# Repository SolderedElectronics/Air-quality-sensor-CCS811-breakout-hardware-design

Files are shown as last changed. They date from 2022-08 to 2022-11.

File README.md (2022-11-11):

# Air quality sensor CCS811 breakout Hardware design

## About the product

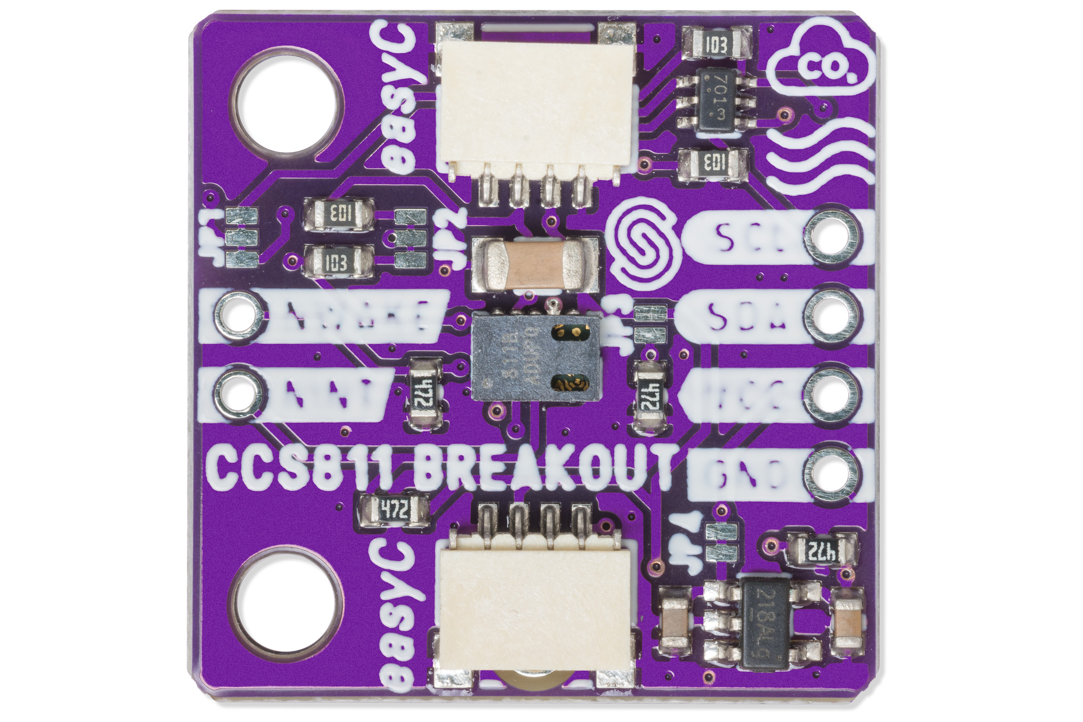
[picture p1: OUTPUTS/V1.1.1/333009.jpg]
Air quality sensor CCS811 breakout
|  |
| :----------------------------------------------------------: |
|      [Buy Air quality sensor CCS811 breakout](https://www.solde.red/333009)      |

The CCS811 sensor is designed to measure various volatile particles in the air (TVOC - Total Volatile Organic Compounds), which include eCO2 (CO2 equivalent) and MOX (metal oxides). VOCs are generally defined as air pollutants, and can come from a variety of sources, starting with ordinary breathing, smoking, coloring, welding, and generally all processes that release particles into the surrounding air.

This sensor is often used to measure indoor air quality, which can work very well and indicate current air pollution, for example, in an office. It communicates via I2C, making it easy to connect, especially through easyC. Sensor itself should be powered for at least 20 minutes to start making accurate readings.

## Repository contents

All Soldered Electronics hardware designed in KiCAD, and repositories are organized in the following way:

- CAD folder - contains KiCAD files (Schematics, Board, Panel Board), sorted by version. Change log lists all changes between versions.
- OUTPUTS - contains useful files, such as Bill of Materials (BOM), PDF of schematics, 3D .step file of the board and gerber files, sorted by version. 
- OUTPUTS -> Compliance - Certificates and useful legal stuff. 

## Want to contribute?

Please feel free to submit a pull request if you have any contributions. We encourage you to submit an issue or pull request if you find a bug. 

## About Soldered

soldered-logo

At Soldered, we design and manufacture a wide selection of electronic products to help you turn your ideas into acts and bring you one step closer to your final project. Our products are intented for makers and crafted in-house by our experienced team in Osijek, Croatia. We believe that sharing is a crucial element for improvement and innovation, and we work hard to stay connected with all our makers regardless of their skill or experience level. Therefore, all our products are open-source. Finally, we always have your back. If you face any problem concerning either your shopping experience or your electronics project, our team will help you deal with it, offering efficient customer service and cost-free technical support anytime. Some of those might be useful for you:

- [Web Store](https://www.soldered.com/shop)
- [Tutorials & Projects](https://soldered.com/learn)
- [Community & Technical support](https://soldered.com/community)

## License info

All Soldered open-source hardware (OSH) is under The TAPR Open Hardware License. Read more in the LICENSE file. 

No warranty - all designs in this repository are distributed in the hope that they will be useful, but without any warranty. They are provided "AS IS", therefore without warranty of any kind, either expressed or implied. The entire quality and performance of what you do with the contents of this repository are your responsibility. In no event, Soldered Electronics will be liable for your damages, losses, including any general, special, incidental or consequential damage arising out of the use or inability to use the contents of this repository. 

## Have fun! 
And thank you from your fellow makers at Soldered Electronics.

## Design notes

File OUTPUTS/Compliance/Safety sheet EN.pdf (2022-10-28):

## Regulatory Compliance and Important Safety Information

PLEASE RETAIN THIS INFORMATION FOR FUTURE REFERENCE.

BEFORE USING THIS PRODUCT, READ ALL INSTRUCTION IN THIS DOCUMENT.

Product name: | Air quality sensor CCS811 breakout
Getting started: | To get started, please visit www.soldered.com

# WARNINGS

- This product should not be covered and should be operated in well ventilated enviroment.
- The product should be placed on a stable, flat, non-conductive surface and should not be contacted by conductive items.
- Connection of other devices may affect compliance or result in damage to the unit, and invalidate the warranty.
- Where peripherals are connected that do not include the cable or connector, the cable or connector used must offer adequate insulation and operation in order that the requirements of the relevant performance and safety requirements are met.
- There is a danger of explosion if the battery is incorrectly placed.
- The product should not be used outside of its specified working range.

# INSTRUCTIONS FOR SAFE USE

To avoid malfunction or damage to your device, please observe the following:
- Do not expose it to water, moisture or place on a conductive surface when turned on. Do not handle the unit with wet hands.
- Do not expose it to heat from any source; the product is designed to be used at normal ambient room temperatures. The product is intended to be used inside.
- Take care when handling to avoid mechanical or electrical damage to any part of the unit. Avoid handling the unit while it's powered. Use ESD protection.
- Use only supplied cable (or the cable of the same or higher quality) with the unit.

# COMPLIANCE INFORMATION

The product complies with the relevant provision of the RoHS Directive for the European Union. In common with all Electrical and Electronic Equipment (EEE), the product should not be disposed household waste.

ELECTROMAGNETIC COMPABILITY AND OPERATION

- The product is in conformity with the protection requirements of EU Council Directive 2014/30/EU on the laws of the Member States relating of electromagnetic compability, and Electromagnetic Compability Regulations 2016 of the UK.
- WARNING: Please do not alter the design of this product, doing so may void your ability to use the product freely, this includes altering the frequency at which product operates.

Soldered Electronics d.o.o., Reisnerova ulica 100, 31000 Osijek, Croatia. VAT ID: HR83200237288

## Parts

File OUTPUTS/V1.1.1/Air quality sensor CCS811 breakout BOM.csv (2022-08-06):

Id | Designator | Package | Quantity | Designation | Supplier and ref
1 | ,,,,,,,,,,,, | buzzardLabel | 13
2 | C1 | 1206C | 1 | 10uF
3 | G*** | Logo-Back-OSH-3.5mm | 1 | LOGO
4 | G*** | Logo-Front-Soldered-3mm | 1 | LOGO
5 | R6,R1,R2,R5 | 0603R | 4 | 4.7k
6 | JP2,JP1 | SMD_JUMPER_3_PAD_TRACE | 2 | SMD_JUMPER_3_PAD_TRACE
7 | R4,R7,R3,R8 | 0603R | 4 | 10k
8 | G*** | Symbol-Front-Air-Quality | 1 | LOGO
9 | JP4 | SMD-JUMPER-CONNECTED_TRACE_SLODERMASK | 1 | SMD-JUMPER-CONNECTED_TRACE_SLODERMASK
10 | U3 | SOT-23-5 | 1 | SE5218
11 | G***,G*** | Logo-Front-easyC-5mm | 2 | LOGO
12 | FD1 | FIDUCIAL_23 | 1 | FIDUCIAL
13 | K3,K4 | easyC-connector | 2 | easyC-SMD
14 | G*** | Symbol-Front-CO2 | 1 | LOGO
15 | C3,C2 | 0603C | 2 | 2.2uF
16 | REF** | Logo-Back-SolderedFULL-15mm | 1 | Logo-Front-SolderedFULL-15mm
17 | U1 | SOT-363 | 1 | NMOS-DUAL
18 | U2 | CCS811 | 1 | CCS811B-JOPR
19 | H2,H1 | HOLE_3.2mm | 2 | HOLE_3.2mm
20 | JP3,JP5 | SMD_JUMPER | 2 | SMD_JUMPER
21 | K1 | HEADER_MALE_2X1 | 1 | HEADER_MALE_2X1
22 | REF** | Version1.1.1. | 1 | Version1.1.1.
23 | K2 | HEADER_MALE_4X1 | 1 | HEADER_MALE_4X1
24 | REF** | Symbol-Front-I2C-ADDR-Field | 1 | Symbol-Front-I2C-ADDR-Field

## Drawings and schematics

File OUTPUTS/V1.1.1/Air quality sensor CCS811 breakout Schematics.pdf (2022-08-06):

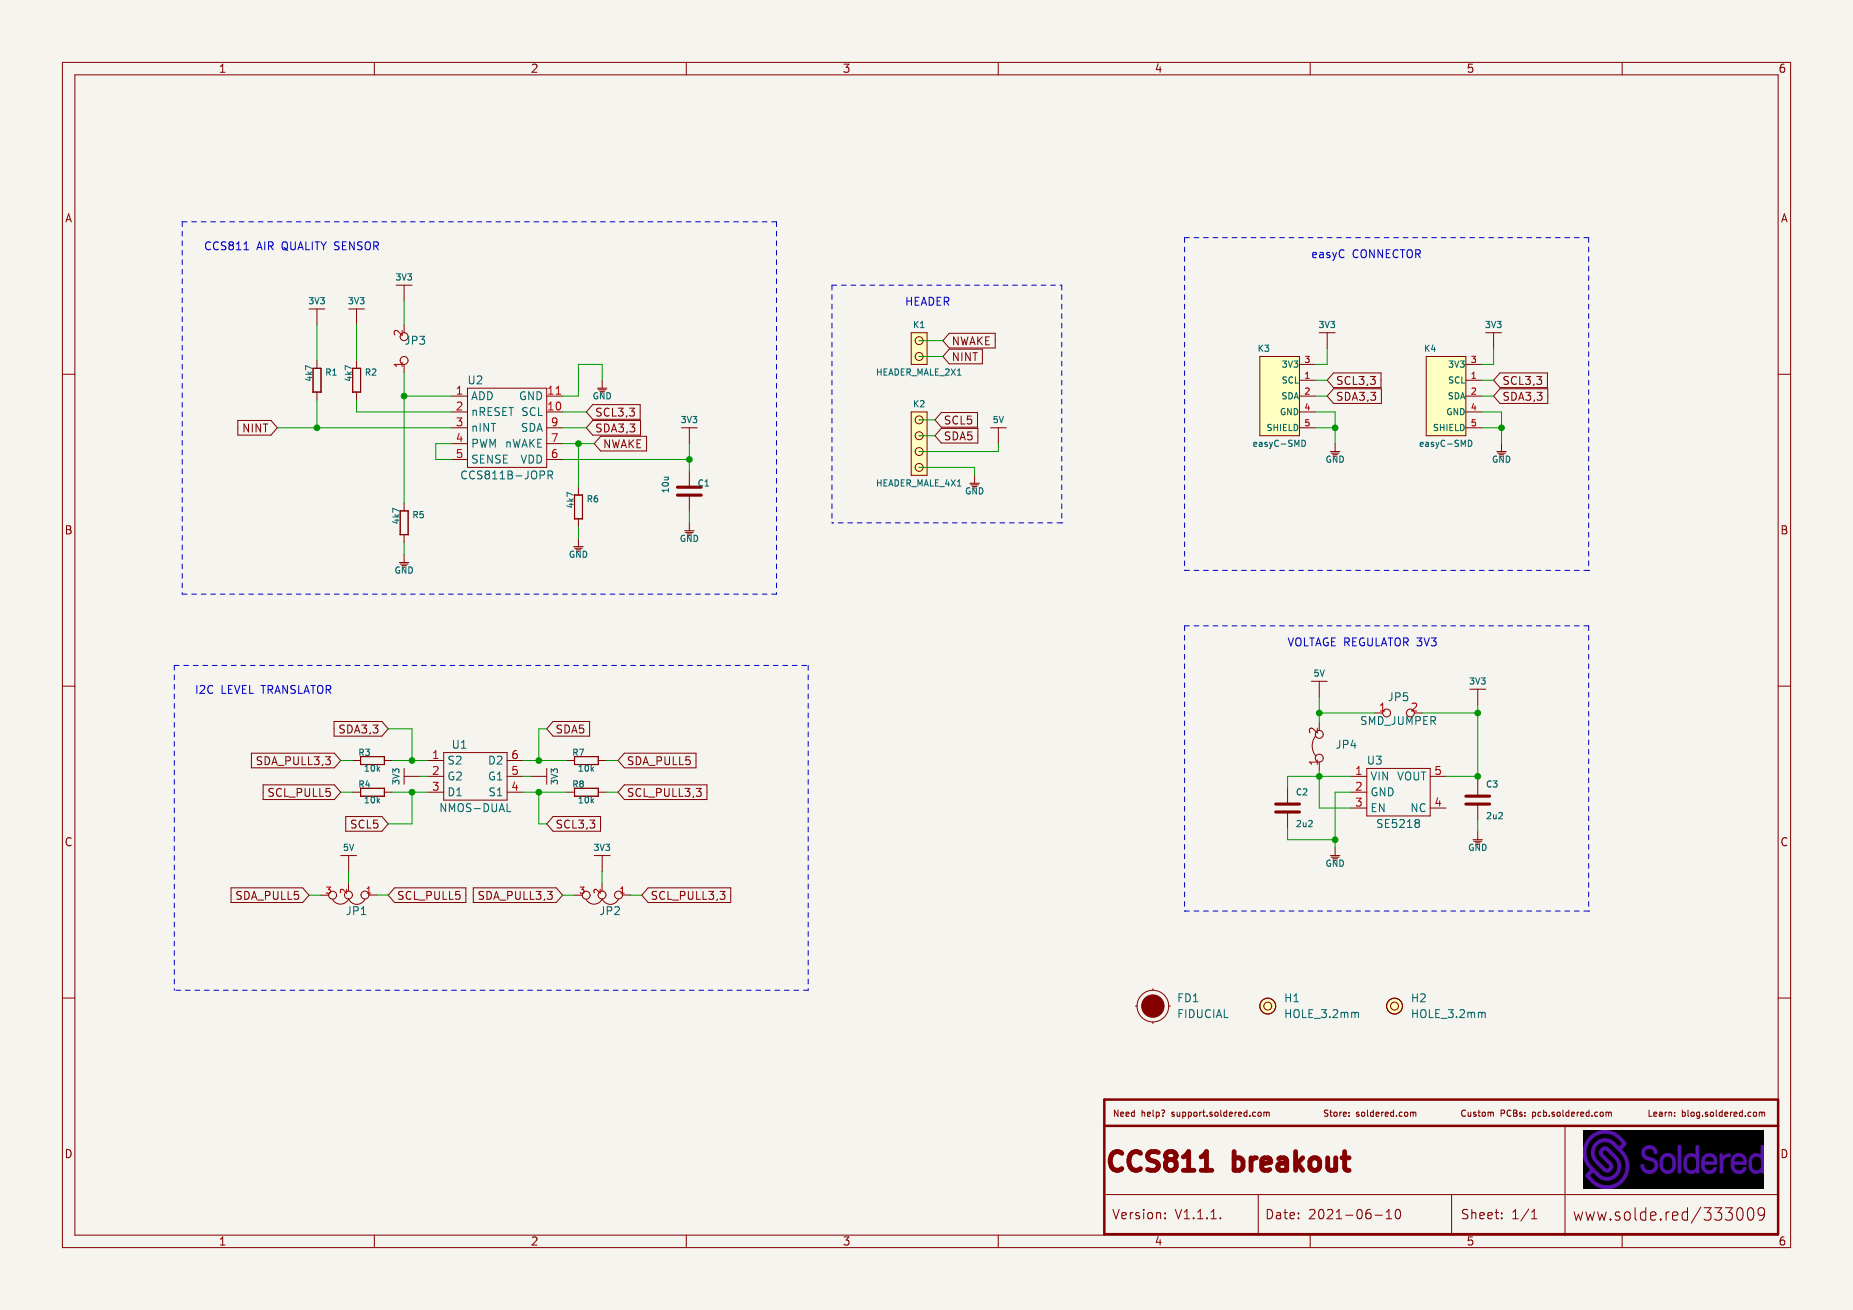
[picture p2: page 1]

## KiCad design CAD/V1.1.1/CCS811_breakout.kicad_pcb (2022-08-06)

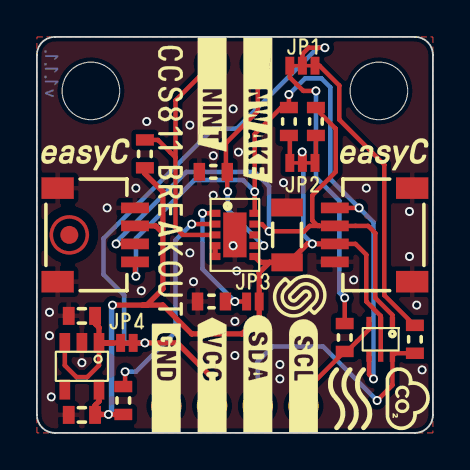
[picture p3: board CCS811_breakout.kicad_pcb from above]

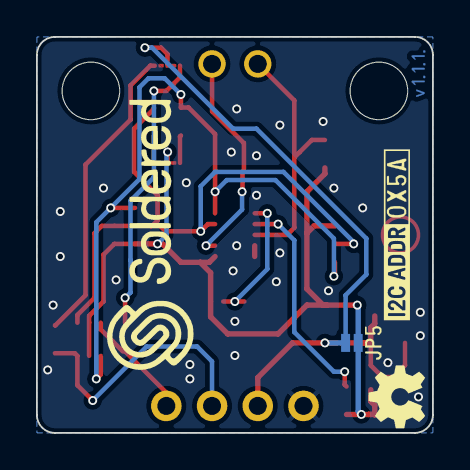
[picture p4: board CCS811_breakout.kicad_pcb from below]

Board: 2 copper layers, 22.0 x 22.0 mm, 26 parts (3 on the bottom side), 17 nets.

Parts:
C1: 10uF; 1206C
C2, C3: 2.2uF; 0603C
FD1: FIDUCIAL; FIDUCIAL_23
H1, H2: HOLE_3.2mm
JP1, JP2: SMD_JUMPER_3_PAD_TRACE
JP3, JP5: SMD_JUMPER
JP4: SMD-JUMPER-CONNECTED_TRACE_SLODERMASK
K1: HEADER_MALE_2X1
K2: HEADER_MALE_4X1
K3, K4: easyC-SMD; easyC-connector
R1, R2, R5, R6: 4.7k; 0603R
R3, R4, R7, R8: 10k; 0603R
U1: NMOS-DUAL; SOT-363
U2: CCS811B-JOPR; CCS811
U3: SE5218; SOT-23-5

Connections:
3V3: C1.2, C3.2, JP2.2, JP3.2, JP5.2, K3.3 (3V3), K4.3 (3V3), R1.2, R2.2, U1.2 (G2), U1.5 (G1), U2.6 (VDD), U3.5 (VOUT)
5V: JP1.2, JP4.2, JP5.1, K2.2
GND: C1.1, C2.1, C3.1, K2.1, K3.4 (GND), K3.5 (SHIELD), K4.4 (GND), K4.5 (SHIELD), R5.1, R6.1, U2.11 (GND), U3.2 (GND)
NINT: K1.1, R1.1, U2.3 (nINT)
NWAKE: K1.2, R6.2, U2.7 (nWAKE)
unnamed: C2.2, JP4.1, U3.1 (VIN), U3.3 (EN)
unnamed: JP3.1, R5.2, U2.1 (ADD)
unnamed: R2.1, U2.2 (nRESET)
unnamed: U2.4 (PWM), U2.5 (SENSE)
SCL3,3: K3.1 (SCL), K4.1 (SCL), R8.1, U1.4 (S1), U2.10 (SCL)
SCL5: K2.4, R4.2, U1.3 (D1)
SCL_PULL3,3: JP2.1, R8.2
SCL_PULL5: JP1.1, R4.1
SDA3,3: K3.2 (SDA), K4.2 (SDA), R3.2, U1.1 (S2), U2.9 (SDA)
SDA5: K2.3, R7.1, U1.6 (D2)
SDA_PULL3,3: JP2.3, R3.1
SDA_PULL5: JP1.3, R7.2

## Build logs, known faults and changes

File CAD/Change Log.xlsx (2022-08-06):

CHANGE LOG
 | Latest version |  |  | v1.1.1.
 |  | Product name: |  | Air quality sensor CCS811 breakout
 |  | Release date: |  | 10.6.2021
 |  | Release author: |  | Ivan
Version: | v1.0.0. | Author: | Ivan | Date: | 4.5.2021.
List of Changes
 | Initial document
Version: | v1.1.1 | Author: | Ivan | Date: | 10.6.2021.
List of Changes
 | Povećani padovi za SE5218
 | CSS811 stavljena veća oznaka prvog pada
 | Povećane oznake jumpera
 | SDA i SCL linije za I2C na 5V zamjenjene na Dual N-MOS da bude ispravno- bilo je krivo spojeno
 | Stavljen jumper kod regulatora da bude bez soldermaska da se lakše može lemiti.
 | Dodana oznaka za I2C adresu 0X5A
